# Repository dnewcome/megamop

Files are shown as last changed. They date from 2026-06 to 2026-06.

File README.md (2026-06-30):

# megamop

A 3D-printable graffiti **mop** (a foam/felt paint dauber, like the old shoe-polish
applicators writers refill with paint) that threads onto a common **Gatorade bottle**.
Big ~2" round tip and a screw-on cap that holds everything together and is swappable.

Two tip closures and two body styles, all sharing one set of parameters:

- **Straight** body (`base.py`) or **angled-neck** body (`base_angled.py`, cup canted
  ~20° so paint feeds the tip when you tilt the bottle toward the wall).
- **Perforated dome cap** (`dome_cap.py`) — a *printed* spherical dome with a grid of
  holes that caps/retains the wick, bulges past the collar for wall contact, and bleeds
  paint through the holes. **No sourced mesh needed.**
- **Flexible TPU dome** (two pieces: `dome_ring.py` rigid + `dome_tpu.py` TPU) — same
  perforated dome but split so the soft face is printed in **TPU** (conforms to brick /
  concrete, won't crack) while a rigid PETG ring keeps a reliable thread. Swappable face.
- Or the simpler **flat collar** (`collar.py`) clamping a separate stainless/Kevlar mesh disc.

### Angled neck + printed dome cap (the current direction)
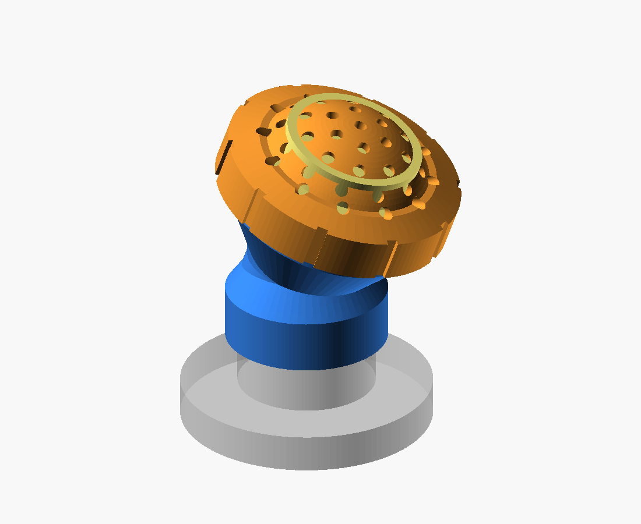
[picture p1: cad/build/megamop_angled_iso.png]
angled assembly

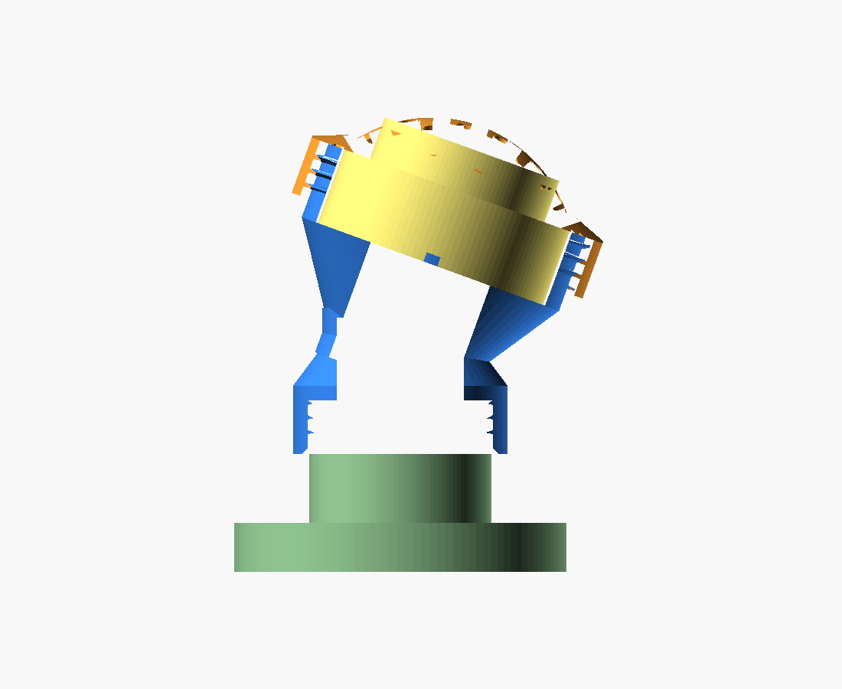
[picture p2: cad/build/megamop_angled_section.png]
angled section


### Straight body + flat collar (v1)
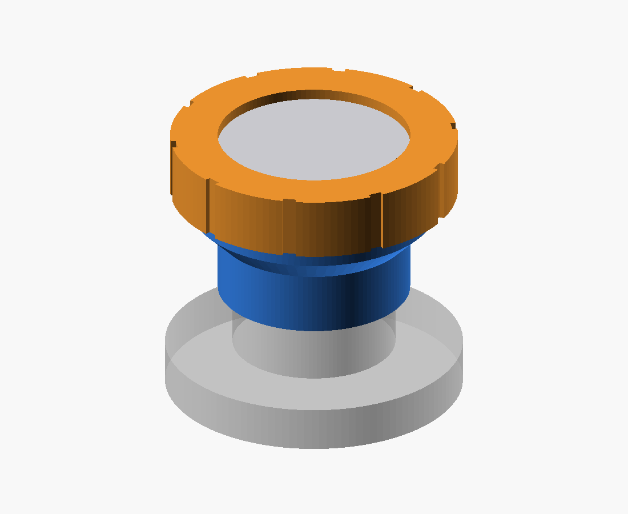
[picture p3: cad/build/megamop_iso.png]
straight assembly


### Snap-on storage cap (keeps the wet dome from drying / smearing)
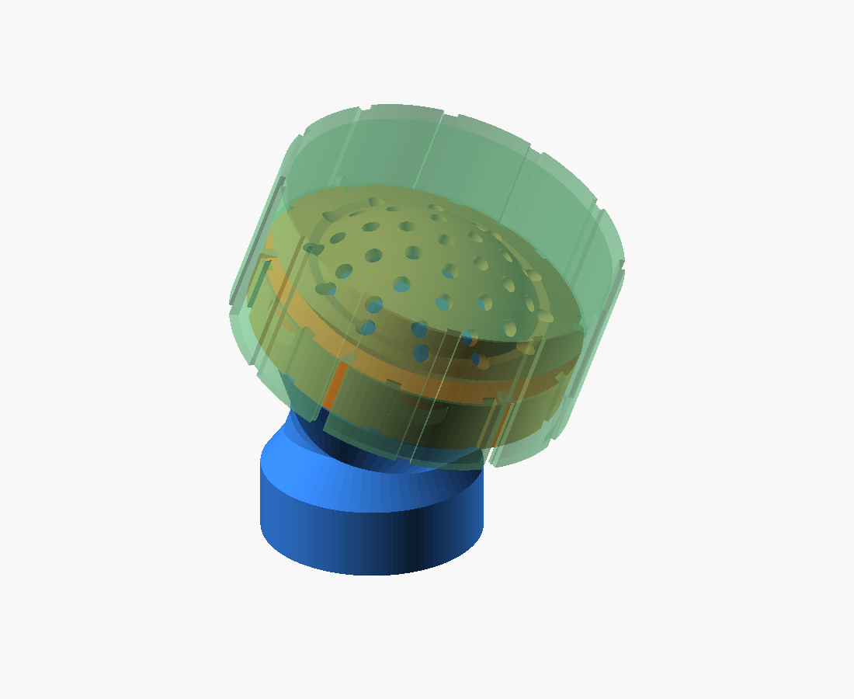
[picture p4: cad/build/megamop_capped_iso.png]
capped


### Flexible TPU dome (rigid ring clamps a soft perforated TPU face)
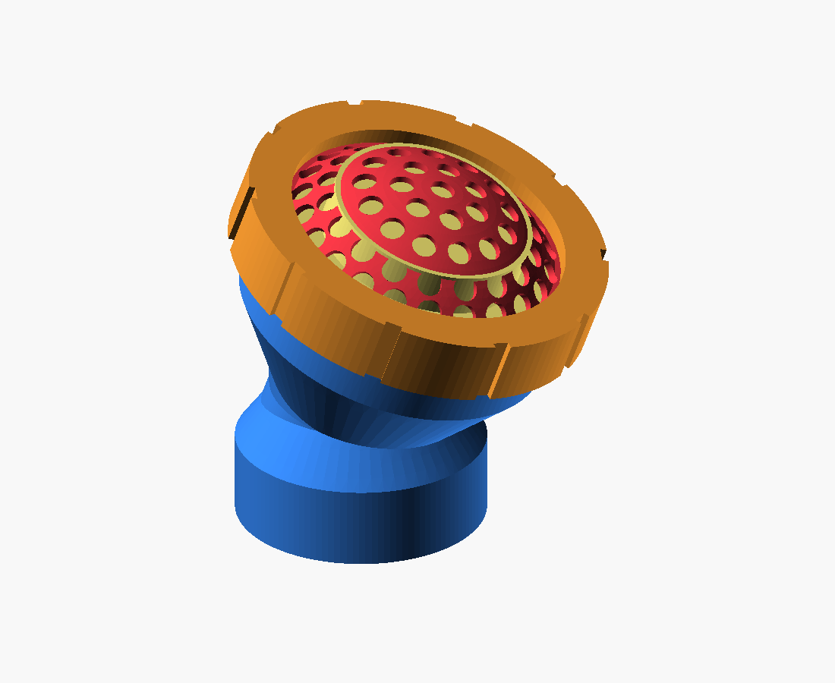
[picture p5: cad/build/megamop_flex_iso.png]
flex


### Textured GLB — the mop on a realistic bottle
`python3 glb_export.py` → **`cad/build/megamop.glb`** (PBR materials: clear bottle + orange
liquid + label, black mop body/ring, red TPU dome; Y-up). Open in Blender, the VS Code glTF
viewer, Windows 3D Viewer, or any three.js viewer — the liquid level shows through the shell.

Photoreal render (headless Blender, via the **product-design** skill):
```
/opt/blender-5.0.1-linux-x64/blender -b -P ~/.claude/skills/product-design/scripts/blender_render.py \
    -- cad/build/megamop.glb cad/build/megamop_blender.png --samples 128
```
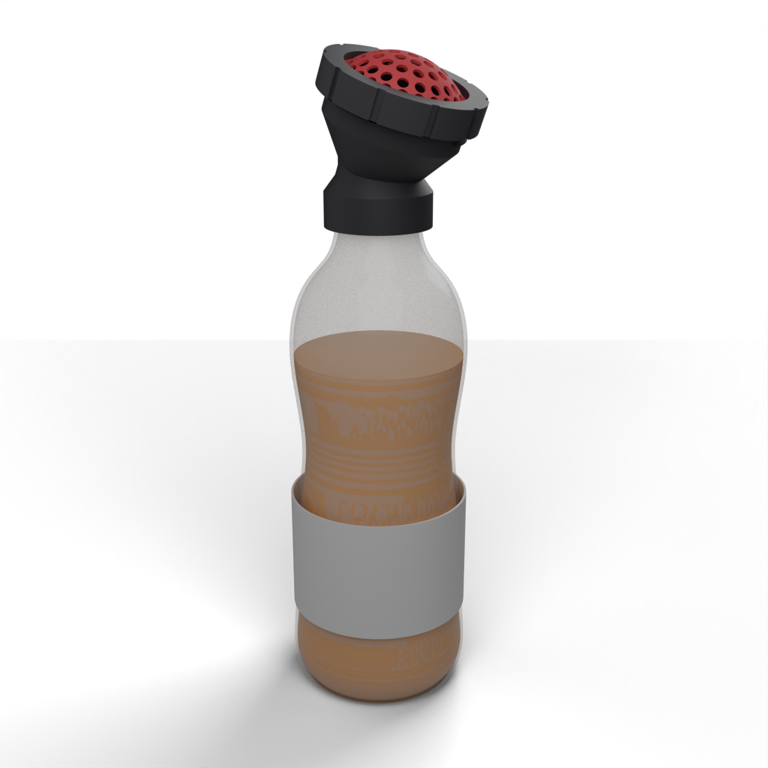
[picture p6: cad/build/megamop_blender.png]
blender hero


360° turntable (`--frames 36 --bg`, stitched with ffmpeg) → `cad/build/megamop_turntable.gif` / `.mp4`:
```
/opt/blender-5.0.1-linux-x64/blender -b -P ~/.claude/skills/product-design/scripts/blender_render.py \
    -- cad/build/megamop.glb cad/build/turntable.png --frames 36 --bg --res 720 --samples 48
ffmpeg -framerate 20 -i cad/build/turntable_%03d.png -vf "palettegen" /tmp/p.png
ffmpeg -framerate 20 -i cad/build/turntable_%03d.png -i /tmp/p.png -lavfi paletteuse -loop 0 cad/build/megamop_turntable.gif
```
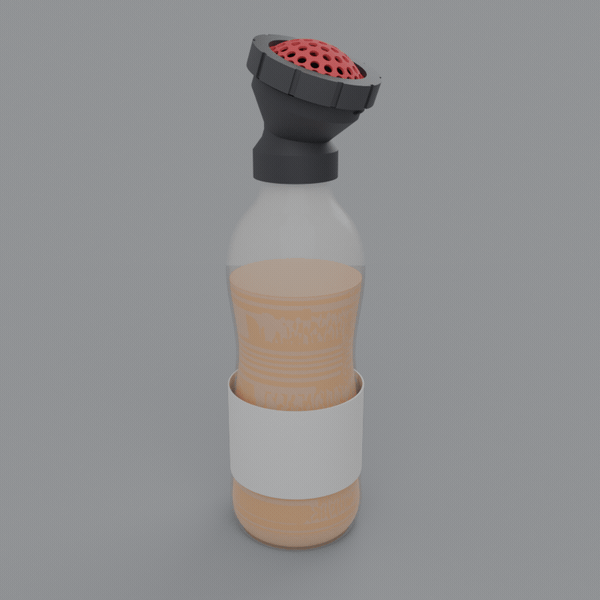
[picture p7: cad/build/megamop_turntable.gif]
turntable


## How it works

| part | what it does |
|---|---|
| **base** / **base_angled** | screws onto the bottle (internal Gatorade thread), feeds paint up a Ø26 passage (bent through a cylinder-elbow on the angled one) into a ~2" wick chamber, carries an **external** thread for the cap |
| **dome_cap** | screws on; perforated spherical dome retains the wick, bulges past the rim, bleeds paint through a hole grid — *fully printed, replaces the mesh* |
| **dome_ring** + **dome_tpu** | flexible 2-piece version: rigid PETG ring (`dome_ring`) clamps a soft **TPU** perforated dome (`dome_tpu`, two flex variants — `stiff`/`soft`) that conforms to the wall and won't crack |
| **collar** *(alt.)* | flat-lip retainer that clamps a separate mesh disc instead of the dome |
| **cap** | push-on storage cover — slips over the dome-cap ring; an internal land stops it at a repeatable depth while tapered friction wedges down the slotted skirt grip the ring (no snap-over), keeping the wick wet and the dome from smearing in a bag |
| wick *(buy)* | ~Ø50 open-cell foam **or** felt pad — holds/meters the paint |
| mesh *(buy, only with collar)* | ~Ø54 stainless/Kevlar disc |

Squeeze the bottle → paint flows through the feed passage, past a **cross-rib backstop**
(keeps the wick from being sucked back into the bottle), saturates the wick, and bleeds
through the dome holes (or mesh) onto the wall.

## ⚠️ Print the test coupon FIRST

The bottle thread is fully pinned: ~38 mm dia (38-400 T/E: 37.19 / 34.80 mm), **2-start**
(two entries 180° apart), **measured pitch 3.0 mm → lead 6.0 mm**. The coupons just dial the
FDM clearance before you commit to the full base:

```bash
cd cad && python3 coupon.py      # -> build/coupon_snug.stl  (clearance 0.30, 1 nub)
                                 #    build/coupon_loose.stl (clearance 0.40, 2 nubs)
```

Print **both** (~12 mm rings), screw onto the bottle, use whichever threads on snug + clean;
put that value in `THREAD_CLEAR_R`. Everything is parameterized in `cad/machine_params.py`,
so once a coupon fits, every part inherits the correct thread.

## Build / regenerate

```bash
cd cad
python3 threads.py        # thread-generator self-test
python3 base.py           # straight body      -> build/base.stl
python3 base_angled.py    # angled-neck body   -> build/base_angled.stl
python3 dome_cap.py       # perforated dome (1pc) -> build/dome_cap.stl
python3 dome_ring.py      # rigid retainer ring   -> build/dome_ring.stl   (PETG)
python3 dome_tpu.py       # flexible perf. dome (TPU) -> dome_tpu_{stiff,soft}.stl + dome_tpu.stl
python3 collar.py         # flat collar (alt.) -> build/collar.stl
python3 cap.py            # snap-on storage cap -> build/cap.stl
python3 machine.py          # straight assembly + renders
python3 machine_angled.py   # angled assembly  + renders
python3 machine_capped.py   # storage cap fitted + renders
python3 machine_flex.py     # two-piece TPU dome + renders
python3 bottle.py           # realistic Gatorade-style bottle (viz only)
python3 glb_export.py       # -> build/megamop.glb  (mop on a bottle, PBR materials)
MACHINE=megamop_angled NOTE=note bash snap.sh   # log a dated render frame
```

All parts self-verify on build (watertight / single-body / bbox printout).

## Print settings (starting point)

- **Material:** PETG (paint-solvent tolerance, toughness) or PLA for a fit test.
- **base / base_angled:** print **skirt-down** (cup opening up). The feed-bore cross-rib
  bridges ~26 mm and may sag (cosmetic). The angled body has a necked elbow — fine skirt-down.
- **dome_cap:** print **ring-down / dome-up**. The dome is a perforated shell, so the
  upper (shallow) portion near the apex may want a touch of support or a well-tuned bridge;
  the holes are small enough to bridge. If it's fussy, drop `DOME_RISE` or add supports.
- **dome_ring:** rigid (PETG/PLA), threads-down. *Never print threads in TPU* — they delaminate
  in shear; that's why the thread lives on this rigid ring and the soft face is a separate part.
- **dome_tpu:** **TPU (~95A)**, flange-down / dome-up. Slow, no/low retraction. Two flex variants
  (`stiff`/`soft`) — print both and pick; soften further with thinner shell or lower durometer.
- **Two-piece tip is two SEPARATE single-material prints** (ring in PETG, dome in TPU) — no
  multi-material needed. If you do one plate: keep them separate objects, assign a filament each,
  and run TPU from the **external spool** (it jams in the AMS). The parts clamp together after.
- **collar:** print **aperture-face-down** (lip flat on the bed).
- **cap:** print **closed-top-down** (flat top on the bed); slots and grip print vertically.
  The internal land's underside is a 45° cone (self-supporting); the taper wedges print as part
  of the skirt. Tune hold with `CAP_WEDGE_INTERF` (friction) and seat depth with `CAP_LAND_IR`.
- 3+ perimeters, 0.2 mm layers. Coarse threads usually print support-free; the coupon confirms.

## Assembly (dome-cap version)

1. Drop the **wick** into the base cup (proud of the rim).
2. Screw the **dome_cap** down — it compresses the wick so the foam mushrooms up through
   the dome throat and presses on the perforated shell.
3. Screw onto a paint-filled Gatorade bottle. Squeeze + drag.

## Key parameters (`cad/machine_params.py`)

`BOTTLE_THREAD_*` (verify w/ coupon) · `WICK_D` 50 (~2") · `CANT_DEG` 20 (angled tilt) ·
`DOME_RISE` 14 / `DOME_T` 2.6 / `DOME_HOLE_D` 3.6 (dome) · `DTPU_T` 1.8 (TPU flex) ·
`CAP_WEDGE_INTERF` 0.5 (cap friction hold) · `CAP_LAND_IR` 27 (cap seat stop) ·
`THREAD_CLEAR_R` 0.35 (FDM fit) · `CUP_THREAD_*` (base↔cap thread).

## Status / deferred
Done: straight + 20° angled bodies; three tip closures (flat collar, 1-piece printed dome,
2-piece rigid-ring + flexible TPU dome, with stiff/soft dome variants); snap-on storage cap;
**bottle thread validated on hardware** (38-400, 2-start, pitch 3.0, thin profile).

## Roadmap / ideas
- **Full 90° neck variant** — `CANT_DEG` bump from 20°; the cylinder-elbow + bored passage will
  need geometry work at 90° (sharper turn, inside-of-bend wall).
- **Dome / screen tweaks** — iterate the perforation + flex after field-testing the soft dome.
- **Trigger-handle pressurized version** *(bigger pivot)* — bottle inverted (gravity feed), a
  trigger to pump/squeeze paint out. Form study + candidate mechanisms in
  [concept-trigger.md](concept-trigger.md) (interesting, mechanism not yet resolved).
- Earlier deferred: chisel/angled *face*, drip control.

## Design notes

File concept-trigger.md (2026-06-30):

# Concept: trigger-bottle paint applicator

A form study (not a working design) for a future direction: a **trigger-handle applicator** with
an **inverted Gatorade bottle** as the paint reservoir, where pulling a trigger meters paint out
the perforated mop dome. Reuses the real bottle + dome for context; body/grip/trigger are notional.

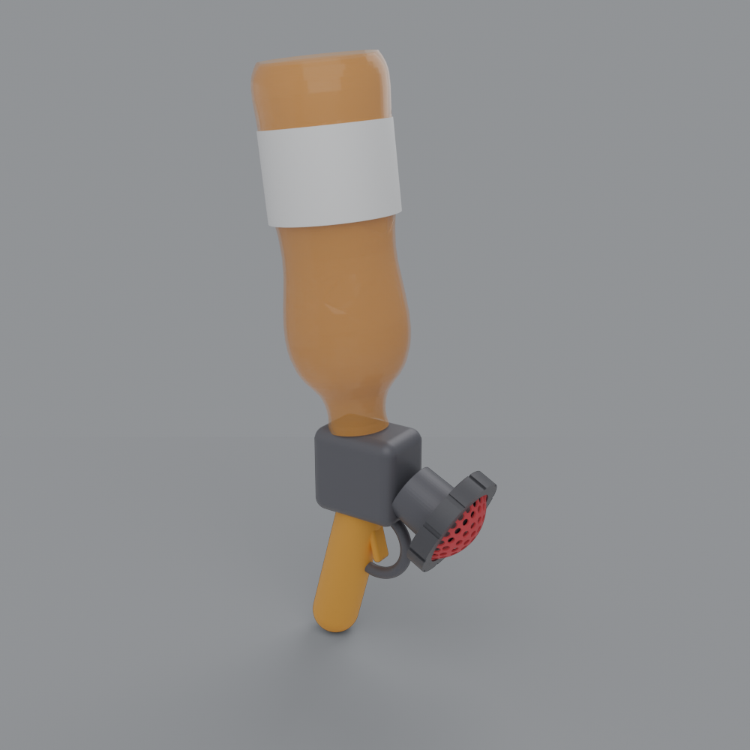
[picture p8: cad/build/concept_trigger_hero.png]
hero

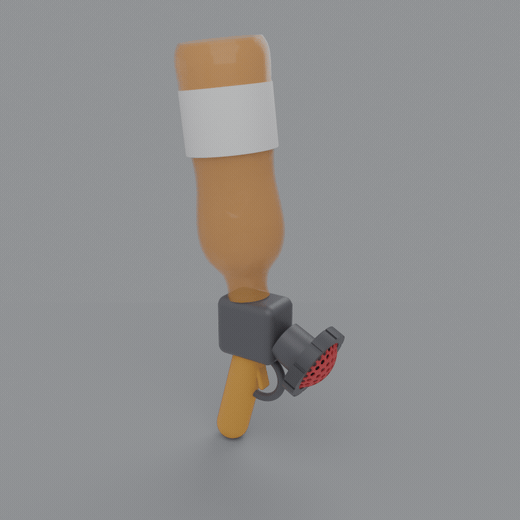
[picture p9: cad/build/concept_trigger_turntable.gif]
turntable


Build it: `python3 cad/concept_trigger.py` → `cad/build/concept_trigger.glb` + render PNGs.
Renders via the `product-design` skill (Blender, `LC_ALL=C`).

## Status: interesting, NOT resolved
The form reads, but it doesn't work as-is — the full-size bottle dominates the ergonomics, and
**the mechanism is the unsolved part.** The crux: get viscous, pigmented paint to flow *on demand*
from an inverted reservoir, hand-triggered, and still be **cleanable**.

## Candidate mechanisms (for whoever picks this up)
1. **Trigger pinch-valve (simplest, most cleanable).** Paint gravity-/squeeze-feeds through a soft
   tube; the trigger pinches the tube to stop flow, releases it to let paint through. Only wetted
   moving part is the tube (cheap to clean/replace). No pump — pressure comes from gravity + a
   bottle squeeze. Effectively adds **drip control** to today's squeeze mop. Good first step.
2. **Diaphragm / piston trigger pump.** Trigger drives a piston or diaphragm in a chamber with two
   **ball check valves** (inlet from reservoir, outlet to tip) + a return spring; meters a shot per
   pull (trigger-sprayer principle). Real flow control, but internal valves clog with paint — needs
   wide bores and tool-free disassembly to clean.
3. **Pressurized reservoir + trigger shutoff.** Pre-pressurize the bottle (hand pump, or just
   squeeze), trigger is only an on/off valve. Needs sealed, pressure-holding joints (o-rings); a
   Gatorade bottle isn't pressure-rated, so low pressure only — and messy if it lets go.

**Shared gotchas:** an inverted bottle dribbles unless there's a **positive shutoff at the tip**;
viscous paint wants **wide passages + cleanable (ball) valves**; o-rings/gaskets are needed
anywhere pressure is held (printed threads alone won't seal).

## Leading idea — trigger-pumped AIR, valve-phased (refined)

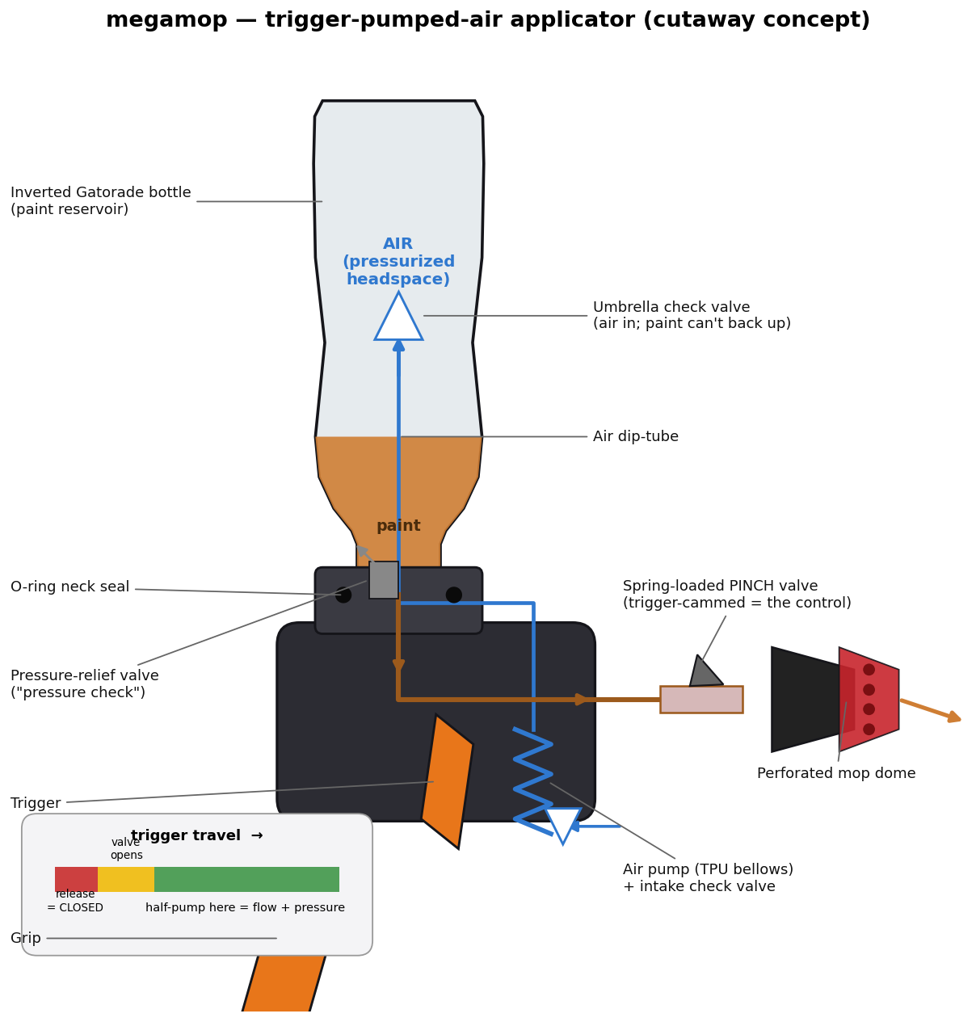
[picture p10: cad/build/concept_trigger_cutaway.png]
cutaway schematic

*(regenerate: `python3 cad/concept_trigger_cutaway.py` — air path blue, paint path amber)*

Pump **air** (not paint) into the inverted bottle's headspace through a dip-tube, pressurizing it
to push paint out the tip; the *same* trigger also gates a pinch valve. **Key win: the pump only
moves air, so it never clogs** — the only paint-wetted moving part is a replaceable pinch tube at
the tip. (It's a pump-pot / pressurized sprayer, with the pump + valve folded into the trigger.)

How it goes together:
- **Air pump on the trigger** — a TPU bellows/diaphragm is ideal (printable, no sliding seal).
- **Intake check valve** — admits air on the return stroke.
- **Air dip-tube up to the headspace**, with a **one-way (umbrella/duckbill) valve at its top** so
  paint can't come back down the air tube when the tool is tilted.
- **Sealed neck cap (o-ring)** so the bottle holds a few psi.
- **Pressure-relief valve** (the "pressure check") to cap pressure — a Gatorade bottle isn't
  pressure-rated, so keep it low.
- **Spring-loaded pinch valve at the tip** — released = pinched (positive shutoff, no dribble);
  pulled = open.

**The trigger "balance" (the clever core):** phase the linkage (cam / lost-motion) so the **valve
opens early in the pull and stays open**, the **air pump strokes through the later travel**, and
the **valve only re-closes at full release**. So you can *half-pump* from a part-pulled position to
keep topping up pressure while paint keeps flowing — the balance described. Tunable via the cam
profile; a MuJoCo sim of the linkage would dial the timing.

Tradeoffs: some paints foam under pressurized air; paint can creep into the air tube if tilted
(umbrella valve mitigates); low pressure only; more parts than a squeeze mop. But pumping air, not
paint, is what makes it practical.

## Pragmatic path
**Pragmatic path:** start with #1 (a trigger pinch-valve for drip control on the existing squeeze
action) — achievable and cleanable — then graduate to #2 if you want true metered pumping. This is
`build123d-machine` territory (multi-part mechanism + mates), and a good candidate for a `kickoff`
to choose pump-vs-pressurized and a MuJoCo sim of the trigger/valve motion before CAD.

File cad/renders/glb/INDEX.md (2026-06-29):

- 0001-blender-hero.png — 2026-06-29 — Blender photoreal: mop on bottle, liquid visible
- 0002-turntable.gif — 2026-06-29 — 36-frame Blender turntable (object-rotate, AgX)

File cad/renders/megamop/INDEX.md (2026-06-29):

- 0001-first-build.png — 2026-06-28 — first-build
- 0002-first-build-section.png — 2026-06-28 — half-section of v1

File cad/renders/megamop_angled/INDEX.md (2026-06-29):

- 0001-domecap.png — 2026-06-29 — angled neck + perforated dome cap
- 0002-domecap-section.png — 2026-06-29 — section

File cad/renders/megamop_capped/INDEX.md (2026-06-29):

- 0001-snap-cap.png — 2026-06-29 — snap-on storage cap over dome

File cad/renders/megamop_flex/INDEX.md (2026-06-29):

- 0001-tpu-dome.png — 2026-06-29 — two-piece flexible TPU dome + rigid ring

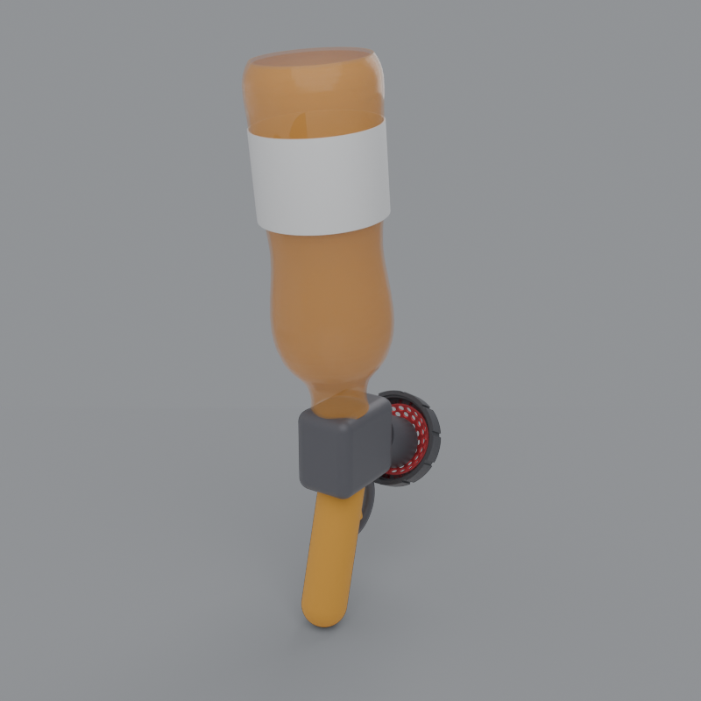
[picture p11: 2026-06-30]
cad/build/concept_sketch_b.png

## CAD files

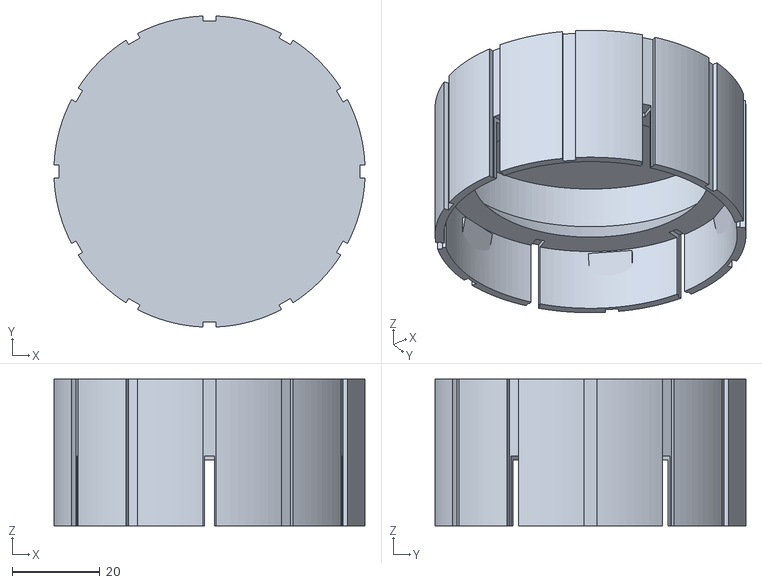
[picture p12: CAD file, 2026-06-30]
cad/build/cap.stl
71.0 x 71.0 x 33.5

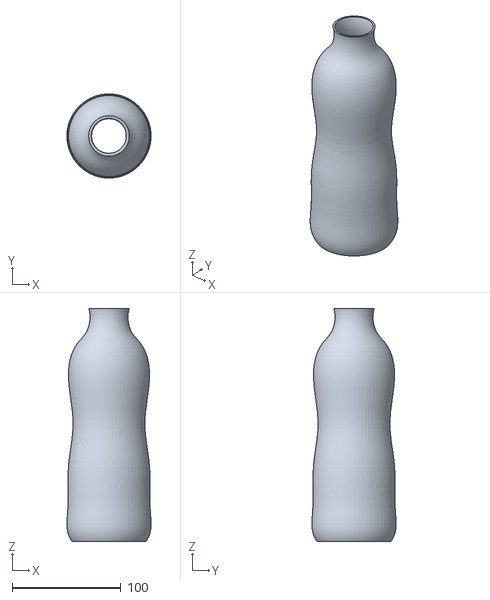
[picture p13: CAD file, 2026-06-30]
cad/build/bottle_shell.stl
77.3 x 77.4 x 214.0

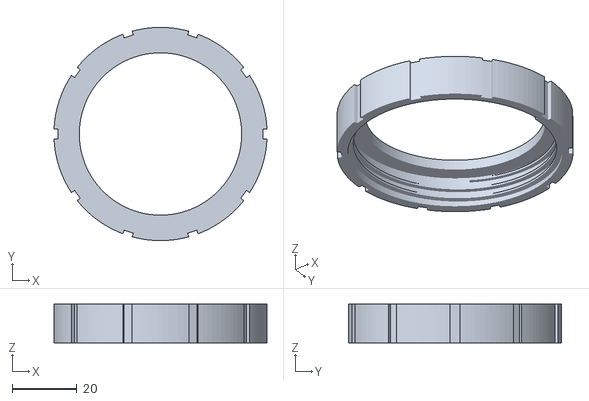
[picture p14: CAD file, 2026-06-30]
cad/build/dome_ring.stl
65.6 x 65.7 x 12.0

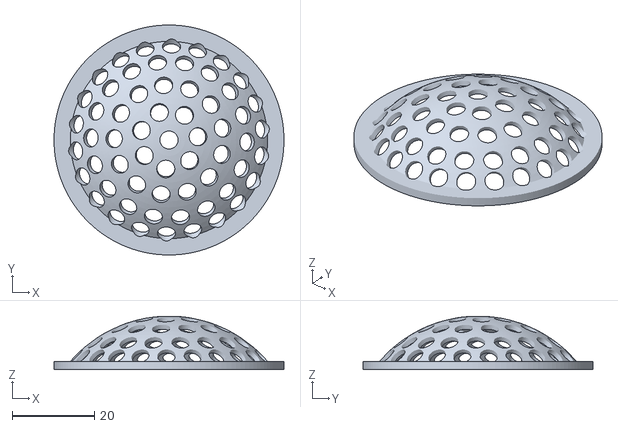
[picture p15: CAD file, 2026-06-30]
cad/build/dome_tpu_soft.stl
56.0 x 56.0 x 12.9

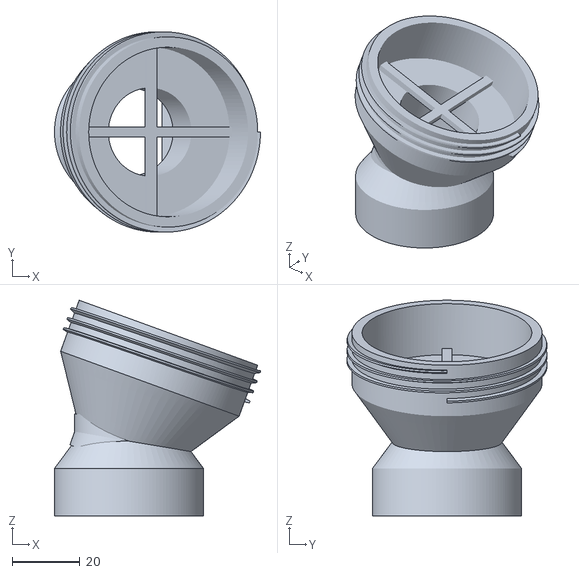
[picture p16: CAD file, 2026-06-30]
cad/build/base_angled.stl
60.7 x 59.0 x 63.5

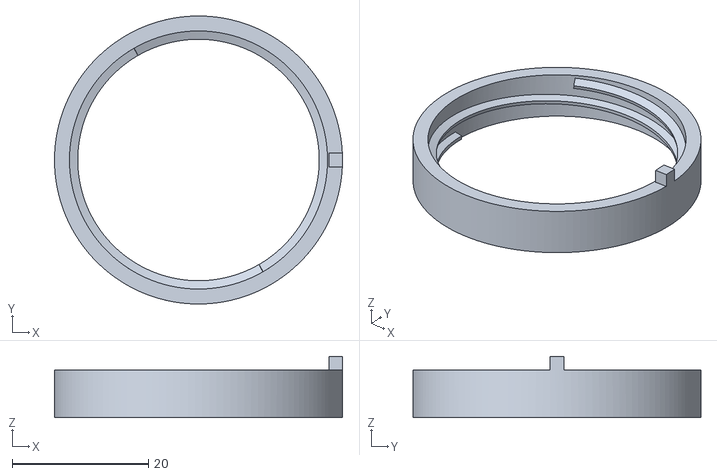
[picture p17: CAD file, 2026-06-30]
cad/build/coupon_thin.stl
42.3 x 42.3 x 9.00

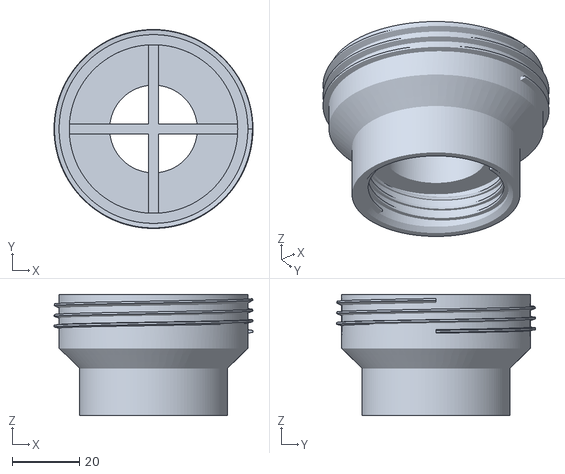
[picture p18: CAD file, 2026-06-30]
cad/build/base.stl
59.0 x 59.0 x 36.0

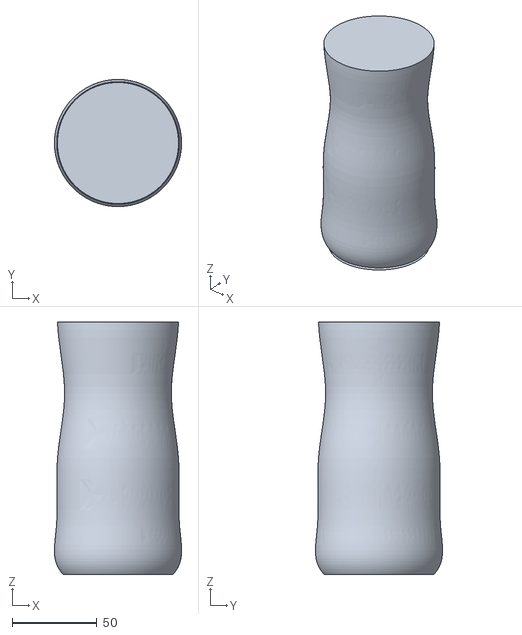
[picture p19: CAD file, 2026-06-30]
cad/build/bottle_liquid.stl
74.8 x 74.8 x 150.0

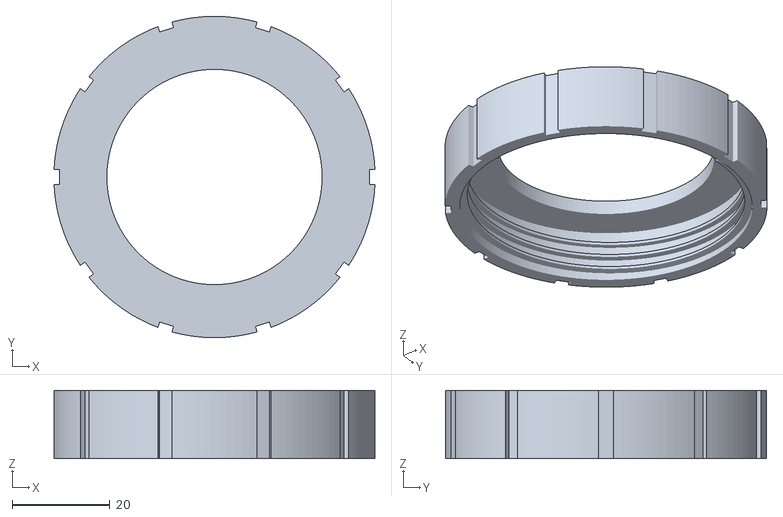
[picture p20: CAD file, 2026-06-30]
cad/build/collar.stl
65.6 x 65.7 x 14.0

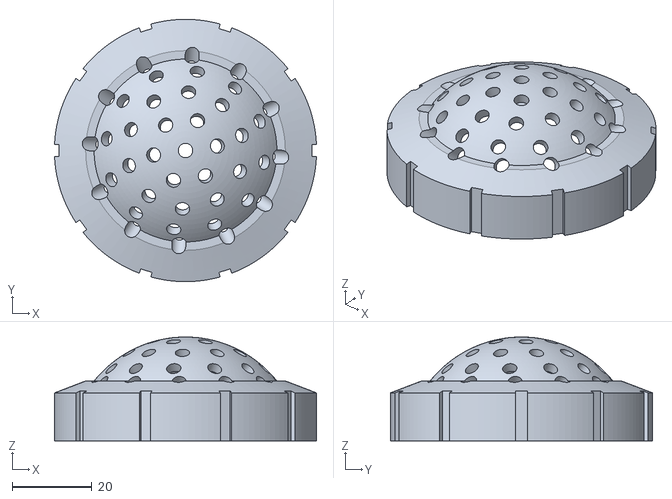
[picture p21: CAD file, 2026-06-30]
cad/build/dome_cap.stl
65.6 x 65.7 x 25.9

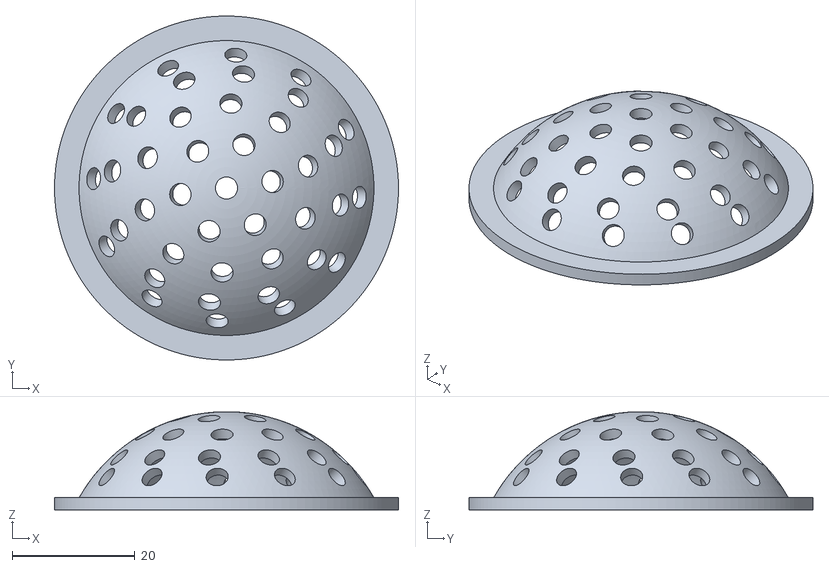
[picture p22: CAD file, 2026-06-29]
cad/build/dome_tpu_stiff.stl
56.0 x 56.0 x 15.9

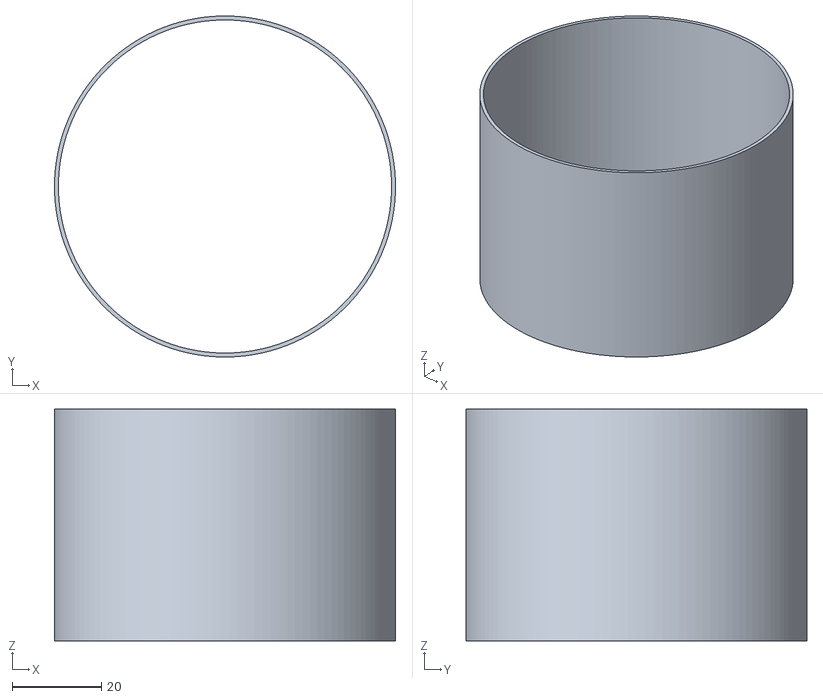
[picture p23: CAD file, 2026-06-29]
cad/build/bottle_label.stl
76.6 x 76.6 x 52.0

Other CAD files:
cad/build/coupon_thinner.stl

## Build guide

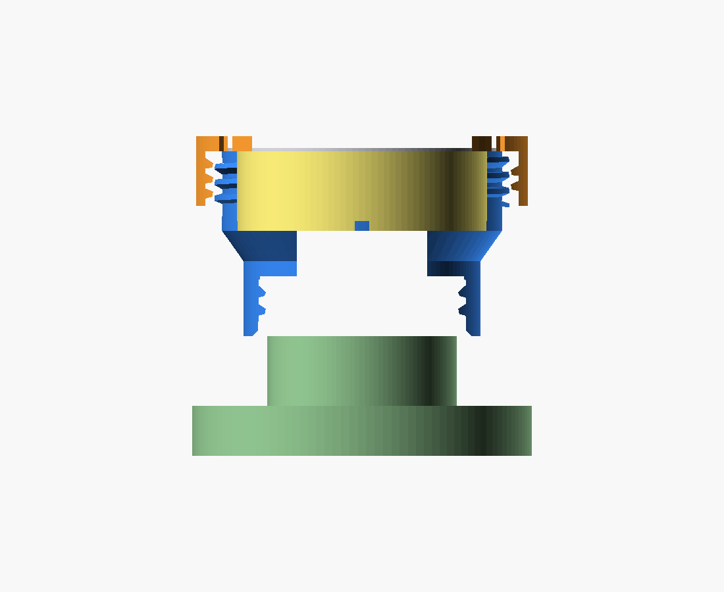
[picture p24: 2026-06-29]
cad/renders/megamop/0002-first-build-section.png

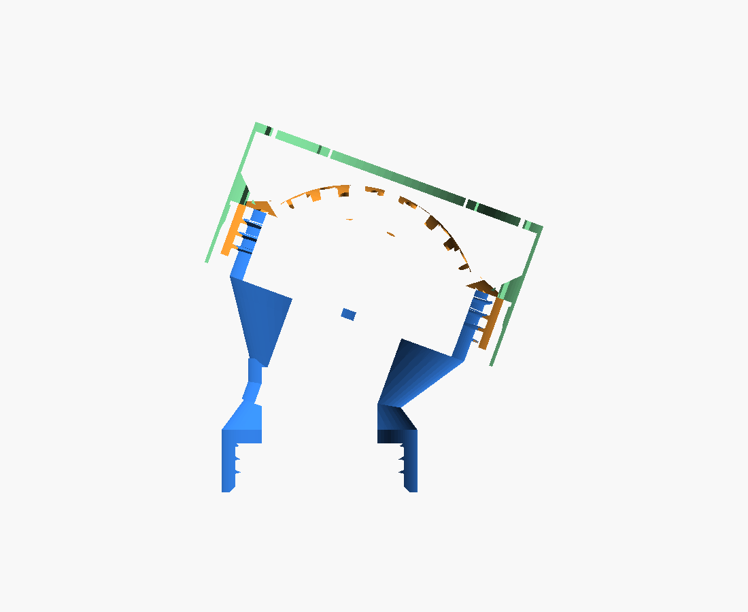
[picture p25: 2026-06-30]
cad/build/megamop_capped_section.png

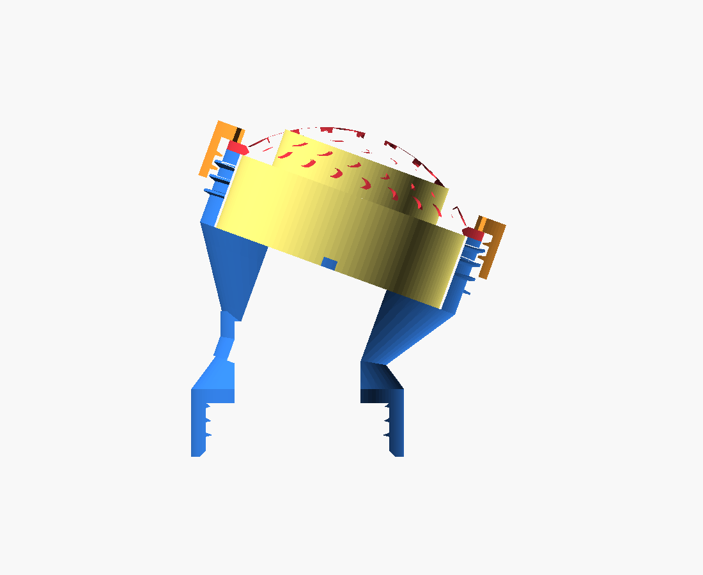
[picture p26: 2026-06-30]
cad/build/megamop_flex_section.png

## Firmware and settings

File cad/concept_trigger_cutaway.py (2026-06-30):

"""concept_trigger_cutaway.py — labeled cutaway schematic of the trigger-pumped-air mechanism.

py cad/concept_trigger_cutaway.py -> build/concept_trigger_cutaway.png (+ .svg)

A 2D engineering cutaway (not CAD) of the leading mechanism: a trigger pumps AIR up a dip-tube
into the inverted bottle's headspace (pressurizing it); the pressure pushes paint to a
trigger-cammed pinch valve and out the perforated dome. Air path = blue, paint path = amber.
Uses the real bottle silhouette (bottle.OUTER).
"""
import os
import matplotlib
matplotlib.use("Agg")
import matplotlib.pyplot as plt
from matplotlib.patches import Polygon, Circle, FancyBboxPatch, Rectangle, FancyArrowPatch
import bottle

PAINT, PAINT_DK = "#cf7e34", "#9c5a1c"
AIR = "#2f78cf"
PLASTIC = "#2c2c33"
ACCENT = "#e8761a"
BPLAST = "#e6ebee"
RED = "#c8242c"
EDGE = "#15151a"

CX, S, Y0 = 40.0, 0.30, 120.0
def yz(z): return Y0 - z * S
def bx(r, side=1): return CX + side * r * S
NECK_Y = yz(214)


def bottle_poly(zmin=0.0, zmax=214.0):
    p = [(bx(r, -1), yz(z)) for r, z in bottle.OUTER if zmin <= z <= zmax]
    p += [(bx(r, +1), yz(z)) for r, z in reversed(bottle.OUTER) if zmin <= z <= zmax]
    return p


def arrow(ax, p0, p1, color, lw=2.6):
    ax.add_patch(FancyArrowPatch(p0, p1, arrowstyle="-|>", mutation_scale=15, lw=lw,
                                 color=color, zorder=7))


def tri(ax, cx, cy, color, up=True, sz=3.0):  # one-way valve glyph
    s = sz if up else -sz
    ax.add_patch(Polygon([(cx - sz, cy - s), (cx + sz, cy - s), (cx, cy + s)],
                         closed=True, facecolor="white", edgecolor=color, lw=1.6, zorder=8))


def lbl(ax, text, xy, xytext, ha):
    ax.annotate(text, xy=xy, xytext=xytext, ha=ha, va="center", fontsize=10, color="#111",
                zorder=11, arrowprops=dict(arrowstyle="-", color="#666", lw=1.0))


def main():
    os.makedirs("build", exist_ok=True)
    fig, ax = plt.subplots(figsize=(12, 12))
    ax.set_xlim(-12, 116); ax.set_ylim(-2, 128); ax.axis("off"); ax.set_aspect("equal")
    ax.set_title("megamop — trigger-pumped-air applicator (cutaway concept)",
                 fontsize=15, fontweight="bold", pad=10)

    # bottle ----------------------------------------------------------------------
    ax.add_patch(Polygon(bottle_poly(), closed=True, facecolor=BPLAST, edgecolor=EDGE, lw=2, zorder=1))
    ax.add_patch(Polygon(bottle_poly(138, 214), closed=True, facecolor=PAINT, alpha=0.9,
                         edgecolor="none", zorder=2))
    ax.text(CX, yz(72), "AIR\n(pressurized\nheadspace)", ha="center", va="center",
            fontsize=11, color=AIR, fontweight="bold", zorder=5)
    ax.text(CX, yz(190), "paint", ha="center", va="center", fontsize=10.5,
            color="#4a2c0c", fontweight="bold", zorder=5)

    # cap + o-ring + relief -------------------------------------------------------
    ax.add_patch(FancyBboxPatch((CX - 11, NECK_Y - 7), 22, 8.5, boxstyle="round,pad=0.2,rounding_size=1",
                                facecolor="#3a3a42", edgecolor=EDGE, lw=1.6, zorder=4))
    for sx in (-7.4, 7.4):
        ax.add_patch(Circle((CX + sx, NECK_Y - 2), 1.1, facecolor="#0a0a0a", zorder=6))
    ax.add_patch(Rectangle((CX - 4, NECK_Y - 2.5), 4, 5, facecolor="#888", edgecolor=EDGE, lw=1, zorder=5))
    arrow(ax, (CX - 2, NECK_Y + 1), (CX - 6, NECK_Y + 5), "#888", 1.6)        # relief vent

    # body / grip / trigger -------------------------------------------------------
    ax.add_patch(FancyBboxPatch((CX - 16, NECK_Y - 32), 42, 26, boxstyle="round,pad=0.3,rounding_size=3",
                                facecolor=PLASTIC, edgecolor=EDGE, lw=1.8, zorder=3))
    ax.add_patch(Polygon([(CX - 13, NECK_Y - 30), (CX - 4, NECK_Y - 30), (CX - 12, NECK_Y - 58),
                          (CX - 21, NECK_Y - 58)], closed=True, facecolor=ACCENT, edgecolor=EDGE, lw=1.6, zorder=2))
    ax.add_patch(Polygon([(CX + 5, NECK_Y - 18), (CX + 10, NECK_Y - 22), (CX + 8, NECK_Y - 36),
                          (CX + 3, NECK_Y - 32)], closed=True, facecolor=ACCENT, edgecolor=EDGE, lw=1.6, zorder=6))

    # AIR pump (bellows) + path to headspace --------------------------------------
    bxp, byt, byb = CX + 18, NECK_Y - 20, NECK_Y - 34
    zig = [(bxp + (2.4 if i % 2 else -2.4), byt - i * (byt - byb) / 7) for i in range(8)]
    ax.plot([p[0] for p in zig], [p[1] for p in zig], color=AIR, lw=3.2, zorder=5)
    arrow(ax, (bxp + 12, byb + 1), (bxp + 4, byb + 1), AIR, 2.0)              # atmosphere intake
    tri(ax, bxp + 4, byb + 1, AIR, up=False, sz=2.4)                          # intake check valve
    ax.plot([bxp, bxp, CX, CX], [byt, NECK_Y - 3, NECK_Y - 3, yz(96)], color=AIR, lw=2.6, zorder=4)
    arrow(ax, (CX, yz(124)), (CX, yz(104)), AIR, 2.6)
    tri(ax, CX, yz(96), AIR, up=True, sz=3.2)                                 # umbrella valve

    # PAINT path: neck -> pinch valve -> dome -------------------------------------
    pinx, piny = CX + 40, NECK_Y - 16
    ax.plot([CX, CX, pinx - 5], [NECK_Y - 2, NECK_Y - 16, piny], color=PAINT_DK, lw=3.4, zorder=4)
    arrow(ax, (CX, NECK_Y - 6), (CX, NECK_Y - 13), PAINT_DK, 2.6)
    arrow(ax, (CX + 14, NECK_Y - 16), (CX + 26, NECK_Y - 16), PAINT_DK, 2.6)
    ax.add_patch(Rectangle((pinx - 5, piny - 1.8), 11, 3.6, facecolor="#d6b8b8",
                           edgecolor=PAINT_DK, lw=1.4, zorder=4))             # pinch tube
    ax.add_patch(Polygon([(pinx, piny + 6), (pinx + 3.5, piny + 2), (pinx - 1, piny + 1.8)],
                         closed=True, facecolor="#666", edgecolor=EDGE, lw=1.2, zorder=7))   # cam
    domx = pinx + 16
    ax.add_patch(Polygon([(domx - 6, piny - 7), (domx - 6, piny + 7), (domx + 5, piny + 4),
                          (domx + 5, piny - 4)], closed=True, facecolor="#222", edgecolor=EDGE, lw=1.4, zorder=4))
    ax.add_patch(Polygon([(domx + 3, piny + 7), (domx + 11, piny + 4), (domx + 11, piny - 4),
                          (domx + 3, piny - 7)], closed=True, facecolor=RED, alpha=0.9, edgecolor=EDGE, lw=1, zorder=5))
    for i in (-4, -1.3, 1.3, 4):
        ax.add_patch(Circle((domx + 7, piny + i), 0.8, facecolor="#7a0f12", zorder=6))
    arrow(ax, (domx + 11, piny), (domx + 20, piny - 3), PAINT, 2.8)          # paint out

    # labels: left column ---------------------------------------------------------
    lbl(ax, "Inverted Gatorade bottle\n(paint reservoir)", (bx(-33), yz(45)), (-12, yz(45)), "left")
    lbl(ax, "O-ring neck seal", (CX - 7.4, NECK_Y - 2), (-12, NECK_Y - 1), "left")
    lbl(ax, "Pressure-relief valve\n(\"pressure check\")", (CX - 4, NECK_Y), (-12, NECK_Y - 14), "left")
    lbl(ax, "Trigger", (CX + 5, NECK_Y - 27), (-12, NECK_Y - 30), "left")
    lbl(ax, "Grip", (CX - 16, NECK_Y - 48), (-12, NECK_Y - 48), "left")
    # labels: right column --------------------------------------------------------
    lbl(ax, "Umbrella check valve\n(air in; paint can't back up)", (CX + 3, yz(96)), (66, yz(96)), "left")
    lbl(ax, "Air dip-tube", (CX, yz(150)), (66, yz(150)), "left")
    lbl(ax, "Air pump (TPU bellows)\n+ intake check valve", (bxp + 2, (byt + byb) / 2), (70, NECK_Y - 40), "left")
    lbl(ax, "Spring-loaded PINCH valve\n(trigger-cammed = the control)", (pinx, piny + 4), (70, NECK_Y - 2), "left")
    lbl(ax, "Perforated mop dome", (domx + 4, piny), (88, NECK_Y - 26), "left")

    # trigger timing inset --------------------------------------------------------
    ix, iy, iw = -10, 6, 46
    ax.add_patch(FancyBboxPatch((ix, iy), iw, 18, boxstyle="round,pad=0.5,rounding_size=2",
                                facecolor="#f4f4f6", edgecolor="#999", lw=1, zorder=9))
    ax.text(ix + iw / 2, iy + 15, "trigger travel  →", ha="center", fontsize=10, fontweight="bold", zorder=10)
    for col, a, b in [("#cc4040", 0, .15), ("#f0c020", .15, .35), ("#52a05a", .35, 1)]:
        ax.add_patch(Rectangle((ix + 4 + a * (iw - 8), iy + 8), (b - a) * (iw - 8), 3.4,
                               facecolor=col, edgecolor="none", zorder=10))
    ax.text(ix + 4 + .07 * (iw - 8), iy + 5.5, "release\n= CLOSED", ha="center", fontsize=7.5, zorder=10)
    ax.text(ix + 4 + .25 * (iw - 8), iy + 12.5, "valve\nopens", ha="center", fontsize=7.5, zorder=10)
    ax.text(ix + 4 + .67 * (iw - 8), iy + 5.5, "half-pump here = flow + pressure", ha="center",
            fontsize=8, zorder=10)

    fig.savefig("build/concept_trigger_cutaway.png", dpi=130, bbox_inches="tight", facecolor="white")
    fig.savefig("build/concept_trigger_cutaway.svg", bbox_inches="tight", facecolor="white")
    print("wrote build/concept_trigger_cutaway.png (+ .svg)")


if __name__ == "__main__":
    main()

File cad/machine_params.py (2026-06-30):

"""machine_params.py — SINGLE SOURCE OF TRUTH for the megamop assembly.

megamop = a 3D-printable graffiti "mop" paint applicator that threads onto a
common Gatorade bottle. Two printed parts:
  - base.py   : screws onto the bottle, carries the wick + mesh, has an external
                thread for the collar
  - collar.py : screws onto the base, clamps the mesh + foam/felt wick

Plus two NON-printed consumables modeled only as assembly stand-ins:
  - a ~2" stainless / Kevlar mesh disc (abrasion face)
  - a ~2" open-cell foam OR felt wick

All shared dimensions live here and are imported, never re-typed.

NOTE ON THE BOTTLE THREAD (the one risky number): the Gatorade "38 mm" finish is
reverse-engineered from community measurements (2-start, ~7.2 coarse thread). The
split between pitch-vs-lead and the exact depth are UNVERIFIED — that is exactly
what cad/coupon.py exists to test on a real bottle. Treat these as a starting
guess; update after the test coupon fits.
"""
from build123d import Location, Pos, Rot

# ---------------------------------------------------------------------------
# 1. GATORADE BOTTLE THREAD  (controlling interface — VERIFY with cad/coupon.py)
# ---------------------------------------------------------------------------
# DIAMETER follows the 38-400 standard (T = 37.19 across peaks, E = 34.80 at root; calipers
# read ~37.5). But the THREAD IS DOUBLE-START: the real bottle has TWO thread entries 180deg
# apart, each wrapping only ~180-200deg -> a 2-START thread (a sports-bottle variant on a 38mm
# neck; the published "400" is single-start, but Gatorade's actual neck is not).
# MEASURED adjacent crest-to-crest spacing along the neck = 3.0mm -> with 2 starts, LEAD = 6.0mm.
BOTTLE_THREAD_MAJOR_D = 37.19      # 38-400 "T", across the thread peaks
BOTTLE_THREAD_ROOT_D  = 34.80      # 38-400 "E", neck OD at the thread root
BOTTLE_THREAD_DEPTH   = (BOTTLE_THREAD_MAJOR_D - BOTTLE_THREAD_ROOT_D) / 2   # ~1.2mm
BOTTLE_THREAD_STARTS  = 2          # DOUBLE-start (two entries 180deg apart) — seen on the bottle
BOTTLE_THREAD_PITCH   = 3.0        # MEASURED adjacent-crest spacing -> LEAD = PITCH*STARTS = 6.0mm
BOTTLE_THREAD_LEN     = 10.0       # threaded engagement length on the neck
BOTTLE_MOUTH_ID       = 31.1       # 38-400 "I" inner diameter (the paint passage)

THREAD_CLEAR_R        = 0.35   # radial clearance, female-vs-male, for FDM fit

# ---------------------------------------------------------------------------
# 2. BASE — bottle skirt (internal Gatorade thread)
# ---------------------------------------------------------------------------
# Internal (female) thread. For the flanks to MESH, the female crest must reach radially
# INWARD to the male ROOT + clearance (NOT the male major) — otherwise the two threads sit
# in disjoint radial bands and the parts slip together without grabbing.
#   male (bottle): crest = MAJOR/2, root = MAJOR/2 - DEPTH
SKIRT_CREST_R = BOTTLE_THREAD_MAJOR_D / 2 - BOTTLE_THREAD_DEPTH + THREAD_CLEAR_R   # female crest
SKIRT_BORE_R  = SKIRT_CREST_R + BOTTLE_THREAD_DEPTH    # bore wall (female root) = MAJOR/2 + clear
SKIRT_WALL    = 3.0
SKIRT_OUTER_R = SKIRT_BORE_R + SKIRT_WALL
SKIRT_H       = BOTTLE_THREAD_LEN + 4.0   # thread length + a lead-in / stop region

# ---------------------------------------------------------------------------
# 3. TIP / WICK CHAMBER  (~2" round mop face)
# ---------------------------------------------------------------------------
WICK_D            = 50.0   # ~2" wick diameter -> chamber ID
WICK_CHAMBER_R    = WICK_D / 2
WICK_CHAMBER_H    = 16.0   # how deep the foam/felt sits in the cup
WICK_PROUD        = 4.0    # uncompressed wick stands proud of the rim (gets squished)
FEED_BORE_D       = 26.0   # paint passage from bottle into the back of the wick
FEED_RIB_W        = 3.0    # cross-rib across the feed bore: backstop so wick can't retract
FEED_RIB_T        = 2.0

CUP_WALL          = 3.0
CUP_OUTER_R       = WICK_CHAMBER_R + CUP_WALL   # 28.0  (rim top is the clamp seat)

# ---------------------------------------------------------------------------
# 4. COLLAR THREAD  (base<->collar — our own choice, made robust/printable)
# ---------------------------------------------------------------------------
CUP_THREAD_PITCH  = 3.0
CUP_THREAD_STARTS = 1
CUP_THREAD_DEPTH  = 1.5
CUP_THREAD_LEN    = 9.0
# External thread on the cup: root sits on the cup outer wall, crest stands proud.
CUP_THREAD_ROOT_R = CUP_OUTER_R                 # 28.0
CUP_THREAD_CREST_R = CUP_THREAD_ROOT_R + CUP_THREAD_DEPTH   # 29.5  (major dia 59)
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

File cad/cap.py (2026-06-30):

"""cap.py — snap-on STORAGE CAP that covers the dome cap (keeps the wick wet / tidy).

py cad/cap.py -> build/cap.stl

The cup thread is occupied by the dome cap, so this cover grabs the dome cap's outer
RING instead. Two-part retention (no snap-over detent):

  - an internal LAND (annular shelf) that the dome-ring TOP face rests against — a positive
    axial stop, so the cap always seats at the same depth and the ring can't over-travel; and
  - tapered WEDGE ribs down the slotted skirt that bear on the ring's OUTER wall with friction
    that GROWS as the cap seats (thin end at the rim, full interference up near the land) and
    RELEASES gradually as you pull it off — continuous friction, not a bump you must clear.

Local frame: z=0 at the open rim, +Z up to the closed top; in use the rim points toward the
bottle. The dome enters through the rim and its ring stops on the land; the dome bulge clears
the land's central opening. Targets the 2-piece dome (dome_ring, flat ring top); also seats on
the 1-piece dome_cap (lands on its frustum a hair higher).
"""
import os
from build123d import (
    Cylinder, Box, Pos, Rot, Align, PolarLocations, BuildPart, BuildSketch,
    BuildLine, Polyline, make_face, revolve, extrude, Axis, Plane, export_stl,
)
import machine_params as M

r_in   = M.CAP_INNER_R                     # slip bore over the ring OD (ring OD + CAP_CLEAR)
r_out  = M.CAP_OUTER_R
ring_od = M.COLLAR_OUTER_R                 # the dome-ring outer wall the wedges grip
H      = M.CAP_CAVITY_H + M.CAP_WALL       # total height (cavity + closed top)
N      = M.CAP_N_SNAP

# Where the dome ring sits inside the cap (cap frame): bottom near the rim, top at the land.
Z_RING_BOT = M.CAP_RIM_BELOW                       # ring bottom edge (rim is CAP_RIM_BELOW lower)
Z_RING_TOP = M.CAP_RIM_BELOW + M.DOME_RING_H       # ring top face -> the land plane
LAND_IR    = M.CAP_LAND_IR

# friction wedge taper: protrusion grows from ~0 at the rim end to CAP_WEDGE_INTERF near the land
Z_WEDGE_BOT = Z_RING_BOT + 1.0
Z_WEDGE_TOP = Z_RING_TOP - 1.0
RIB_W       = 10.0                          # tangential width of each wedge rib
WELD        = 1.0                           # overlap into the wall so fuses are clean (no slivers)

SLOT_W = 2.2
SLOT_H = Z_RING_TOP + 1.0                    # slots span the whole rib+land zone -> the segments flex


def _land():
    """Annular shelf the dome-ring TOP rests on; 45deg back-chamfer (closed-top side) prints clean."""
    ramp = (r_in + WELD) - LAND_IR
    pts = [
        (LAND_IR,       Z_RING_TOP),         # land face inner edge (ring rests here)
        (r_in + WELD,   Z_RING_TOP),         # ...out into the wall (overlap weld)
        (r_in + WELD,   Z_RING_TOP + ramp),  # 45deg ramp up the closed-top side
    ]
    with BuildPart() as lp:
        with BuildSketch(Plane.XZ):
            with BuildLine():
                Polyline(*pts, close=True)
            make_face()
        revolve(axis=Axis.Z)
    return lp.part


def _wedge_ribs():
    """N tapered ribs: inner face ramps from inside the wall (flush) to ring_od-INTERF near the land."""
    r_top = ring_od - M.CAP_WEDGE_INTERF     # inner radius at the seated (max-grip) end
    ribs = []
    for k in range(N):
        th = 360.0 * k / N
        with BuildPart() as wp:
            with BuildSketch(Plane.XZ):      # X = radial, Z = axial
                with BuildLine():
                    Polyline(
                        (r_in + WELD, Z_WEDGE_BOT),   # buried in the wall at the rim end
                        (r_in + WELD, Z_WEDGE_TOP),
                        (r_top,       Z_WEDGE_TOP),   # max protrusion at the land end
                        close=True,
                    )
                make_face()
            extrude(amount=RIB_W / 2, both=True)
        ribs.append(Rot(0, 0, th) * wp.part)
    return ribs


def part():
    C = (Align.CENTER, Align.CENTER, Align.MIN)
    body = Cylinder(r_out, H, align=C)
    body -= Cylinder(r_in, M.CAP_CAVITY_H, align=C)        # open cavity from the rim up
    body = body.fuse(_land())                              # internal land = positive seated stop
    body = body.fuse(*_wedge_ribs())                       # friction taper ribs

    # flex slots through the skirt, staggered between the ribs so each segment carries one rib
    slots = []
    for k in range(N):
        th = 360.0 * k / N + 360.0 / (2 * N)
        slot = Rot(0, 0, th) * Pos(r_in, 0, 0) * Box(
            2 * M.CAP_WALL + 2, SLOT_W, SLOT_H, align=(Align.CENTER, Align.CENTER, Align.MIN))
        slots.append(slot)
    body = body.cut(*slots)

    # grip flutes on the outside
    with BuildPart() as fp:
        with PolarLocations(r_out, 12):
            Box(2.4, 3.0, H, align=C)
    body = body.cut(*fp.solids())
    return body


MATES = {
    "rim": Pos(0, 0, 0),    # open rim; placed ~CAP_RIM_BELOW under the dome-cap ring
}

if __name__ == "__main__":
    os.makedirs("build", exist_ok=True)
    p = part()
    export_stl(p, "build/cap.stl")
    import trimesh
    m = trimesh.load("build/cap.stl")
    print("cap:", (m.bounds[1] - m.bounds[0]).round(2),
          "bodies:", len(m.split(only_watertight=False)),
          "watertight:", m.is_watertight)

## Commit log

2026-06-29 megamop: 3D-printable refillable graffiti mop for a Gatorade bottle
    Parametric build123d CAD for a refillable paint dauber ("mop") that threads
    onto a common Gatorade bottle: straight + 20-degree angled-neck bodies, a
    printed perforated dome tip (rigid one-piece, or rigid ring + flexible TPU
    two-piece), a snap-on storage cap, and bottle-thread test coupons. Includes
    GLB export + headless Blender product renders/turntable, and a thread-mesh
    verifier (verify_threads.py) that asserts the male/female threads engage.
    [base.stl, base_angled.stl, bottle_label.stl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]
2026-06-30 Validated bottle thread (38-400, 2-start, pitch 3.0) + thin profile + softer dome
    Bottle interface now confirmed on a real Gatorade bottle:
    - diameter 38-400 (Ø37.19 major / Ø34.80 root), female anchored on the measured root
    - 2-start, MEASURED pitch 3.0mm / lead 6.0mm (community "2-start/7.2" was wrong; physically confirmed)
    - thread ridge thinned to 40% of pitch — fat 80% ridges bound on the bottle's thick male
    threads (also the cause of the earlier cup/collar binding)
    Also: flatter/thinner TPU dome that conforms with less wall pressure (both stiff+soft variants
    kept), coupon repurposed to dial the thread profile, and verify_threads asserts engagement.
    Regenerated all STLs, assembly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
    [base.stl, base_angled.stl, bottle_liquid.stl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]
2026-06-30 Capture trigger-bottle concept (form study + candidate mechanisms)
    Conceptual massing model of a trigger-handle applicator with an inverted Gatorade-bottle
    reservoir and the perforated mop dome (cad/concept_trigger.py -> GLB + Blender hero/turntable/
    sketches). Form reads but won't work as-is; the mechanism is unresolved. concept-trigger.md
    writes up three candidate mechanisms (pinch-valve / diaphragm pump / pressurized + shutoff)
    and the viscous-paint + cleanability + tip-shutoff challenges.
2026-06-30 concept-trigger: refined leading mechanism — trigger-pumped air + valve phasing
2026-06-30 Add cutaway schematic of the trigger-pumped-air mechanism
    cad/concept_trigger_cutaway.py -> labeled 2D cutaway (matplotlib): air path (blue) pumped up a
    dip-tube into the inverted bottle's headspace, paint path (amber) down to a trigger-cammed pinch
    valve and out the dome, with check/umbrella/relief valves and a trigger-timing inset showing the
    "half-pump to keep flow + pressure" balance. Embedded in concept-trigger.md.
    [concept_trigger_cutaway.py]
2026-06-30 Redesign storage cap: friction-taper + land stop (replaces snap detents)
    The protective cap printed "too tight to go on" — the snap detents needed
    ~1mm of skirt flex to clear the ring in stiff PETG. Reworked retention from a
    binary snap-over into a continuous friction fit with a positive seat:
    - internal LAND (CAP_LAND_IR 27): annular shelf the dome-ring top rests on, so
    the cap seats at a repeatable depth and can't over-travel; 45° back-chamfer
    prints clean upside-down, central opening clears the dome bulge.
    - tapered WEDGE ribs (CAP_WEDGE_INTERF 0.5): six ribs down the slotted skirt
    whose protrusion grows flush->0.5mm from rim to land — slides on free, friction
    ramps over the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
    [cap.stl]
